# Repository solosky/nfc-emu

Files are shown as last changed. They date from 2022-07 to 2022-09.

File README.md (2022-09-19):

# nfc-emu

这是一个可以模拟NTAG215的模拟器。
可以用来模拟Amiibo和门禁卡。
硬件理论上支持Mifare的卡片，但目前固件不支持。

## 功能

* 支持最多10张卡模拟
* 支持模拟Amiibo
* 4秒无响应自动断电

## PCB 

| RevA | RevB |
| --- | --- |
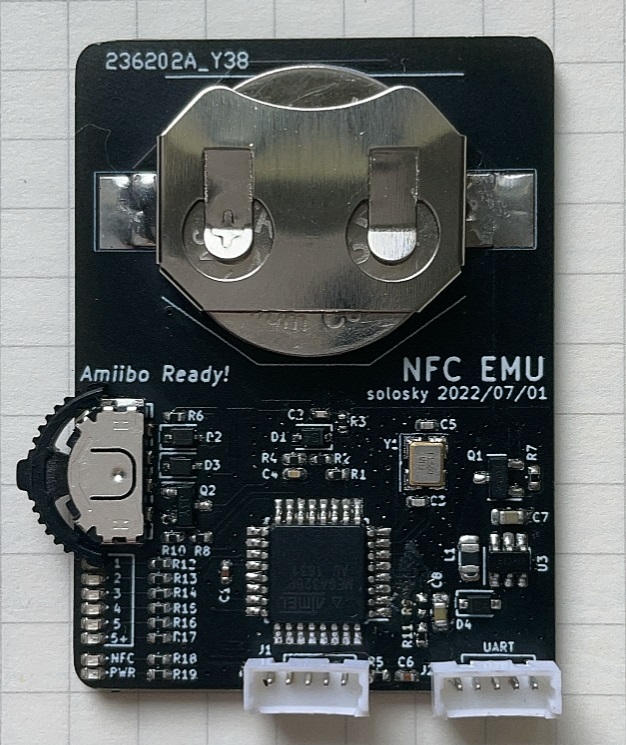
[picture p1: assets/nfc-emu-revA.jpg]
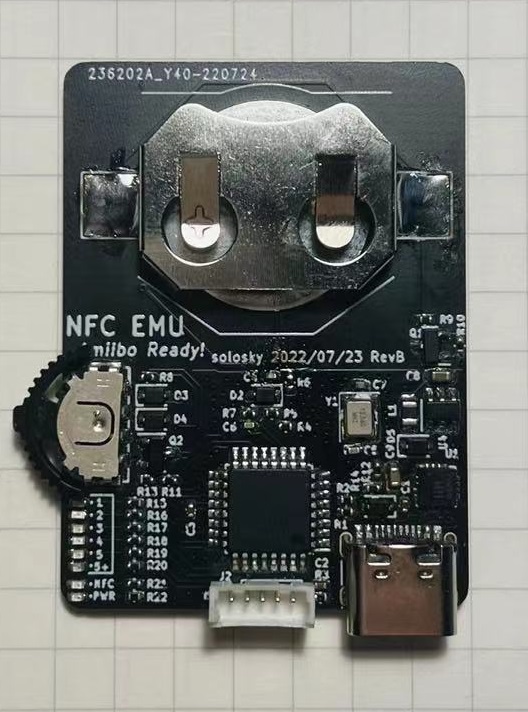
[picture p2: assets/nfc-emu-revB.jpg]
|  |  | 
| 可用 | 和RevA相比新增了CH343P串口芯片，可以直接通过USB下载固件。注意：RevB未能完整测试，使用慎重！！|

## 演示

(https://player.bilibili.com/player.html?aid=688118575&bvid=BV1D24y1Z7Rh&cid=835047325&page=1)

## 固件编译和烧写

本固件是基于Ardunio框架实现的，所以固件烧写方法很类似。
主要分两步，第一步刷入bootloader, 第二步使用串口刷入固件。
bootloader只需要刷写一次即可，之后的固件更新可以直接用串口刷入新固件。

### 刷入Bootloader

需要的软件：progisp 
需要的硬件：USB ISP
* assets/optiboot_flash_atmega328p_UART0_115200_13560000L_B1.hex 刷入MCU中。
* 修改熔丝位：低位值：0xCE, 高位值：0xDE，扩展位：0xFF
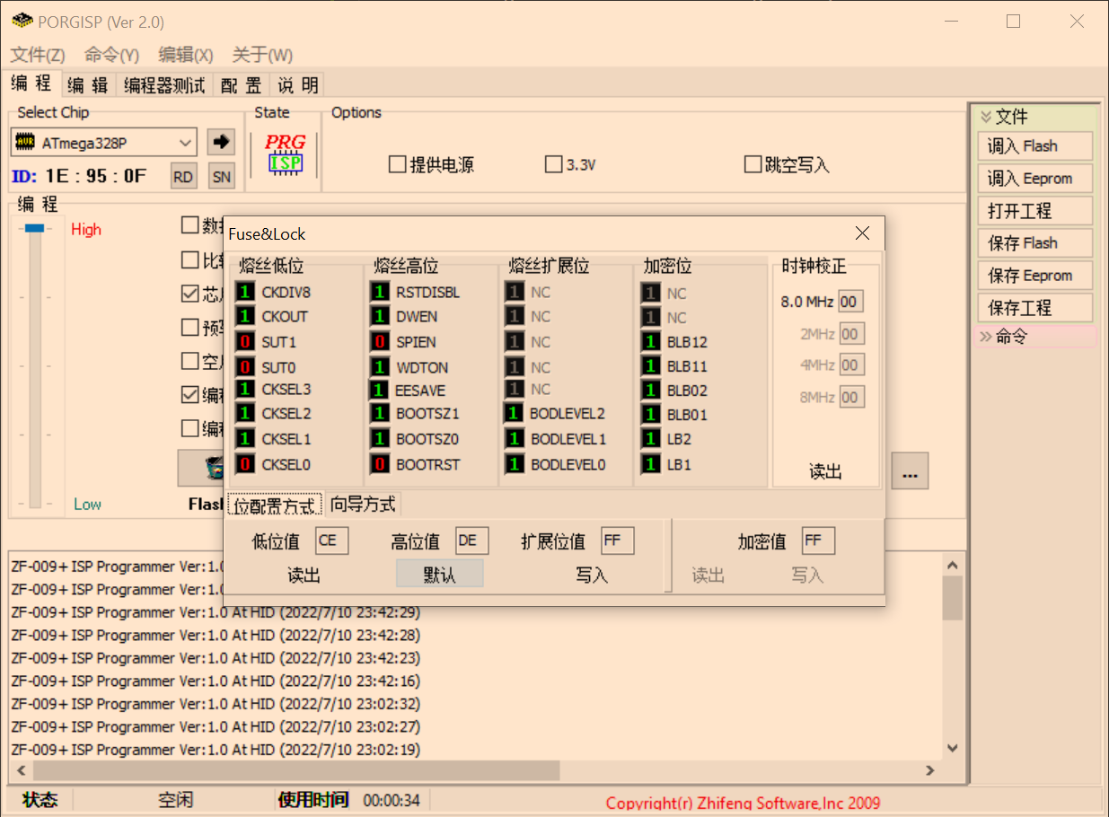
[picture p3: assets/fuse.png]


连接左边标记为ISP的接口到USB ISP烧写器上，接线顺序如下：

CLK MOSI MISO RESET GND 

注意需要把电池安装上，在刷入bootloader过程中需要一直按住中键打开电源。

刷入步骤：
 1. 先点击 编程熔丝 后面的框，弹出熔丝对话框，点击读出按钮读出当前值，然后依次输入 低位值：0xCE, 高位值：0xDE，扩展位：0xFF，点击写入执行写入操作
 2. 点击文件 -> 调入flash, 选择assets/optiboot_flash_atmega328p_UART0_115200_13560000L_B1.hex，点击自动按钮写入bootloader

### 编译固件

首先需要下载 vscode, 安装platformio插件，并安装arduino框架。

因为用了非标准的13.56M的晶振，需要新建一个board。
在 C:\Users\{{用户名}}\.platformio\platforms\atmelavr\boards下面新建一个文件 ATmega328PNfcEmu.json， 内容如下：

```
{
  "build": {
    "core": "MiniCore",
    "extra_flags": "-DARDUINO_AVR_ATmega328P",
    "f_cpu": "13560000L",
    "mcu": "atmega328p",
    "variant": "standard"
  },
  "bootloader": {
    "led_pin": "B5"
  },
  "debug": {
    "simavr_target": "atmega328p",
    "avr-stub": {
      "speed": 115200
    }
  },
  "frameworks": [
    "arduino"
  ],
  "name": "ATmega328P/PA NFC EMU",
  "upload": {
    "maximum_ram_size": 2048,
    "maximum_size": 32768,
    "protocol": "arduino",
    "require_upload_port": true,
    "speed": 115200
  },
  "url": "https://www.microchip.com/wwwproducts/en/ATmega328P",
  "vendor": "Microchip"
}
```

使用vscode打开项目的fw文件夹，platformio插件会自动启动识别为一个platformio的项目。
点击编译按钮就可以完成编译。

### 刷入固件

刷入固件使用vscode的platformio插件完成。

#### RevA 

需要额外一个带DTR信号的USB转串口的模块，连接右边的UART接口按如下顺序连接USB串口模块。

+5V TXD RXD DTR GND 

注意：TXD连串口模块的RXD，RXD连串口模块的TXD。

#### RevB 

自带了的USB转串口模块，直接插上USB线，系统自动识别出串口设备。

#### 刷入步骤

刷入之前，修改platformio.ini中的 upload_port，monitor_port的值为设备的串口号。
点击上传按钮就可以下载固件到设备中。

## 支持的卡

硬件上支持14443-3A的低速卡，比如NTAG215, Mifare等常见卡。
软件层面目前只支持模拟NTAG215，Mifare卡暂时不支持。

## 功耗

目前使用中耗电量为22mA，CR2032勉强能使用，还需要进一步优化电路减少功耗。

因为设计了断电电路，不使用基本不耗电，使用时间取决于使用次数。

注意：一定要使用南孚的传应CR2032电池，其他电池不一定能提供这么大的放电电流！

## 写入TAG

可以用手机APP写入，也可以用PN532等NFC读写器写入。

### 使用手机APP写入

如果手机支持NFC，可以下载如下软件写入Amiibo:

iOS: AppleStore搜索Umiibo写入。
Umiibo是收费软件，但只需要6元RMB，没有应用内购买，很良心的APP的，强烈推荐购买。

Andriod: https://github.com/HiddenRamblings/TagMo/releases 下载最新版本的TAGMO安装。

如果以上都没有，可以购买PN532模块，然后安装Linux虚拟机，将PN532 USB设备接入虚拟机后，执行如下命令写入标签。

### 安装libnfc 

```
sudo apt update
sudo apt install libnfc-dev
```

### Amiibo写入
```
nfc-mfultralight w "SSB Zelda.bin" --full
NFC device: pn532 opened
1 ISO14443A passive target(s) found:
	040402cb5d6480
Using MIFARE Ultralight card with UID: 040402cb5d6480
WARNING: Tag is EV1 or NTAG - PASSWORD may be required
NTAG Type: NTAG215 (504 user bytes)
Checking if UL badge is DirectWrite...
 Original Block 0 (Pages 0-2): 0404028acb5d648072480000
 Original UID: 040402cb5d6480
 Attempt to write Block 0 (pages 0-2) ...
  Writing Page 0: 04 04 02 8a
  Writing Page 1: cb 5d 64 80
  Writing Page 2: 72 48 00 00
 Block 0 written successfully
Card is DirectWrite
Writing 135 pages |.......................................................................................................................................|
Done, 135 of 135 pages written (0 pages skipped, 0 pages failed).

```

默认固件所有标签都是空白的，需要用APP写入标签才能使用。

## 操作说明

* 关机状态下短按中键开机，电源指示灯亮起
* 开机状态下短按上，下键切换标签
* 开机状态下长按中键2秒以上重置标签，uid也会随机生成，标签指示灯会短闪两次
* 开机状态下靠近读卡器读取标签 

可以使用重置标签操作结合APP来无限刷Amiibo!

注意：写入和重置标签会产生Flash的写入操作，一般来说Flash的写入操作是有次数限制的，按ATMEGA328p的手册来说，每扇区至少有10000次写入寿命，所以每个标签的至少能刷写10000次左右（重置和写入算两次操作），超过这个次数当前标签的数据可能永久无法写入。

后续可以考虑实现写均衡来充分利用剩余未使用的空间来提高标签的写入次数。
 
# 感谢 

此项目是移植 [Simple NFC](https://github.com/Nonannet/simple-nfc)，主要的模拟代码来源SimpleNFC，感谢 @Nonannet 提供的代码，非常棒的实现！

# 欢迎加群讨论 

QQ群：109761876

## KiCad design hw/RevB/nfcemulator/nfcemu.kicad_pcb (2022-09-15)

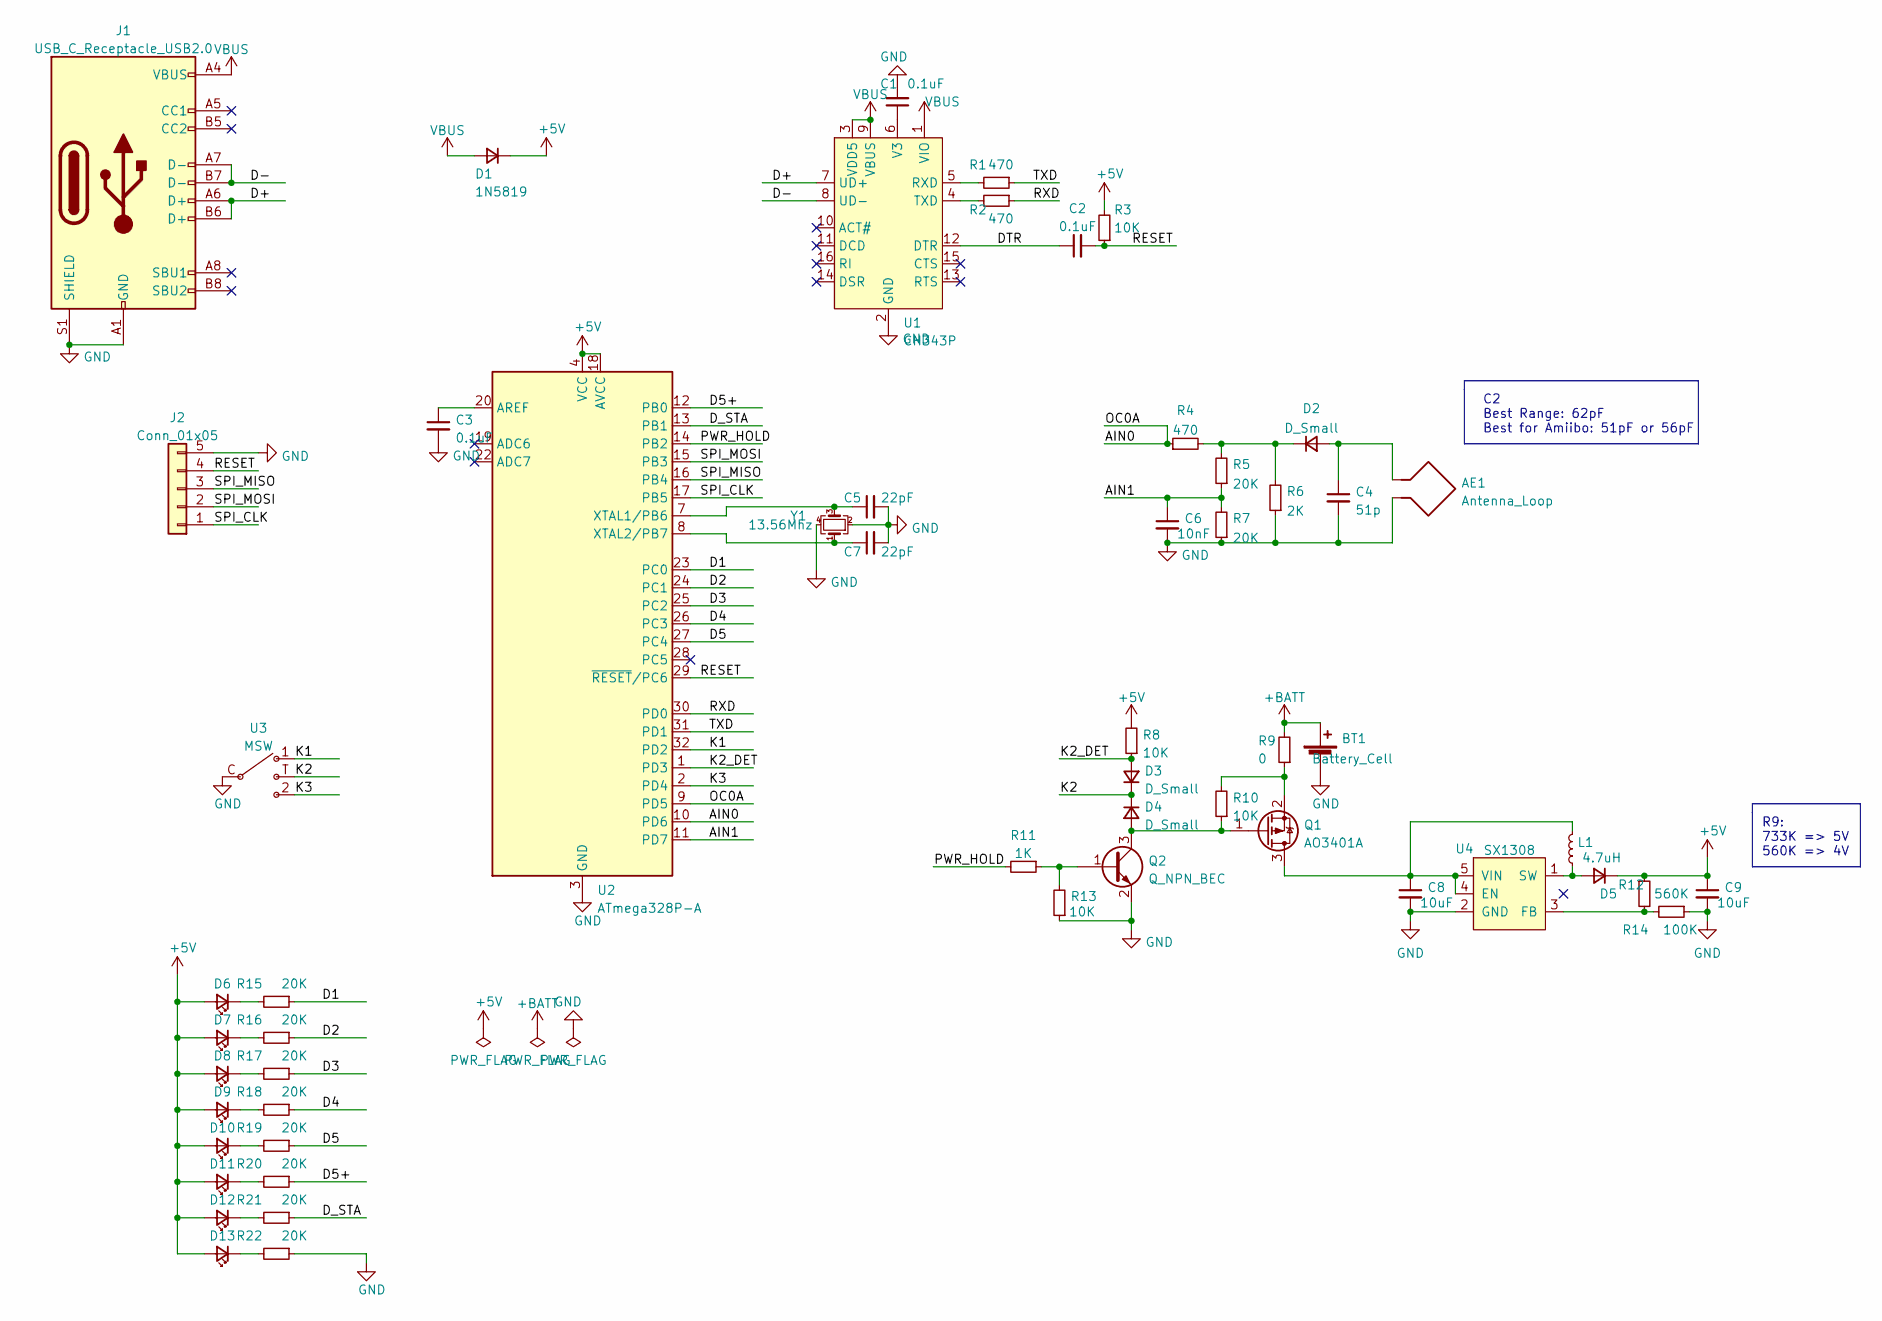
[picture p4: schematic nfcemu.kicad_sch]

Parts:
AE1: Antenna_Loop; NFC_ANT2
BT1: Battery_Cell; BatteryHolder_Keystone_3002_1x2032
C1, C2, C3: 0.1uF; C_0402_1005Metric
C4: 51p; C_0402_1005Metric
C5, C7: 22pF; C_0402_1005Metric
C6: 10nF; C_0402_1005Metric
C8, C9: 10uF; C_0603_1608Metric
D1: 1N5819; D_SOD-323
D2, D3, D4, D5: D_Small; D_SOD-323
D6, D7, D8, D9, D10, D11, D12, D13: LED_Small; LED_0402_1005Metric
J1: USB_C_Receptacle_USB2.0; USB_C_Receptacle_HRO_TYPE-C-31-M-12
J2: Conn_01x05; PinHeader_1x05_P1.27mm_Vertical
L1: 4.7uH; L_0805_2012Metric
Q1: AO3401A; SOT-23
Q2: Q_NPN_BEC; SOT-23
R1, R2, R4: 470; R_0402_1005Metric
R3, R8, R10, R13: 10K; R_0402_1005Metric
R5, R7, R15, R16, R17, R18, R19, R20, R21, R22: 20K; R_0402_1005Metric
R6: 2K; R_0402_1005Metric
R9: 0; R_0402_1005Metric
R11: 1K; R_0402_1005Metric
R12: 560K; R_0402_1005Metric
R14: 100K; R_0402_1005Metric
U1: CH343P; QFN-16-1EP_3x3mm_P0.5mm_EP1.45x1.45mm
U2: ATmega328P-A; TQFP-32_7x7mm_P0.8mm
U3: MSW
U4: SX1308; TSOT-23-6
Y1: 13.56Mhz; Crystal_SMD_3225-4Pin_3.2x2.5mm

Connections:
+5V: C9.1, D1.1 (K), D5.1 (K), D6.2 (A), D7.2 (A), D8.2 (A), D9.2 (A), D10.2 (A), D11.2 (A), D12.2 (A), D13.2 (A), R3.2, R8.2, R12.1, U2.4 (VCC), U2.6 (VCC), U2.18 (AVCC)
+BATT: BT1.1 (+), R9.2
/AIN0: R4.1, U2.9 (PD5), U2.10 (PD6)
/AIN1: C6.1, R5.1, R7.2, U2.11 (PD7)
/D1: R15.1, U2.23 (PC0)
/D2: R16.1, U2.24 (PC1)
/D3: R17.1, U2.25 (PC2)
/D4: R18.1, U2.26 (PC3)
/D5: R19.1, U2.27 (PC4)
/D5+: R20.1, U2.12 (PB0)
/D+: J1.A6 (D+), J1.B6 (D+), U1.7 (UD+)
/D-: J1.A7 (D-), J1.B7 (D-), U1.8 (UD-)
/DTR: C2.1, U1.12 (DTR)
/D_STA: R21.1, U2.13 (PB1)
/K1: U2.32 (PD2), U3.1
/K2: D3.1 (K), D4.1 (K), U3.T
/K2_DET: D3.2 (A), R8.1, U2.1 (PD3)
/K3: U2.2 (PD4), U3.2
/PWR_HOLD: R11.2, U2.14 (PB2)
/RESET: C2.2, J2.4, R3.1, U2.29 (~RESET/PC6)
/RXD: R2.1, U2.30 (PD0)
/SPI_CLK: J2.1, U2.17 (PB5)
/SPI_MISO: J2.3, U2.16 (PB4)
/SPI_MOSI: J2.2, U2.15 (PB3)
/TXD: R1.1, U2.31 (PD1)
GND: AE1.1, BT1.2 (-), C1.2, C3.2, C4.2, C5.2, C6.2, C7.2, C8.2, C9.2, J1.A1 (GND), J1.A12 (GND), J1.B1 (GND), J1.B12 (GND), J1.S1 (SHIELD), J2.5, Q2.2 (E), R6.1, R7.1, R13.1, R14.1, R22.1, U1.2 (GND), U1.17 (EP), U2.3 (GND), U2.5 (GND), U2.21 (GND), U3.C, U4.2 (GND), Y1.2, Y1.4
unnamed: AE1.2, C4.1, D2.2 (A)
unnamed: C1.1, U1.6 (V3)
unnamed: C3.1, U2.20 (AREF)
unnamed: C5.1, U2.7 (XTAL1/PB6), Y1.3
unnamed: C7.1, U2.8 (XTAL2/PB7), Y1.1
unnamed: C8.1, L1.2, Q1.3 (D), U4.4 (EN), U4.5 (VIN)
unnamed: D2.1 (K), R4.2, R5.2, R6.2
unnamed: D4.2 (A), Q1.1 (G), Q2.3 (C), R10.1
unnamed: D5.2 (A), L1.1, U4.1 (SW)
unnamed: D6.1 (K), R15.2
unnamed: D7.1 (K), R16.2
unnamed: D8.1 (K), R17.2
unnamed: D9.1 (K), R18.2
unnamed: D10.1 (K), R19.2
unnamed: D11.1 (K), R20.2
unnamed: D12.1 (K), R21.2
unnamed: D13.1 (K), R22.2
unnamed: Q1.2 (S), R9.1, R10.2
unnamed: Q2.1 (B), R11.1, R13.2
unnamed: R1.2, U1.5 (RXD)
unnamed: R2.2, U1.4 (TXD)
unnamed: R12.2, R14.2, U4.3 (FB)
unnamed: U3.5, U3.6, U3.7, U3.8
VBUS: D1.2 (A), J1.A4 (VBUS), J1.A9 (VBUS), J1.B4 (VBUS), J1.B9 (VBUS), U1.1 (VIO), U1.3 (VDD5), U1.9 (VBUS)

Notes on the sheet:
R9: 733K => 5V 560K => 4V
C2 Best Range: 62pF Best for Amiibo: 51pF or 56pF

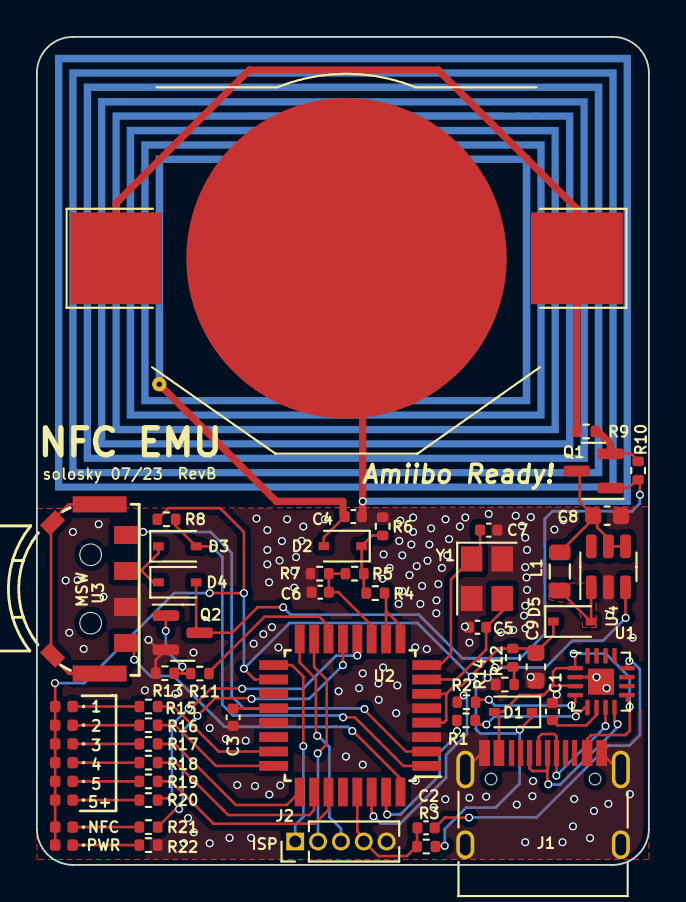
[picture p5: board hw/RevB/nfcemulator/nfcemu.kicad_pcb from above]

Board: 2 copper layers, 34.0 x 46.0 mm, 56 parts (1 on the bottom side), 50 nets.

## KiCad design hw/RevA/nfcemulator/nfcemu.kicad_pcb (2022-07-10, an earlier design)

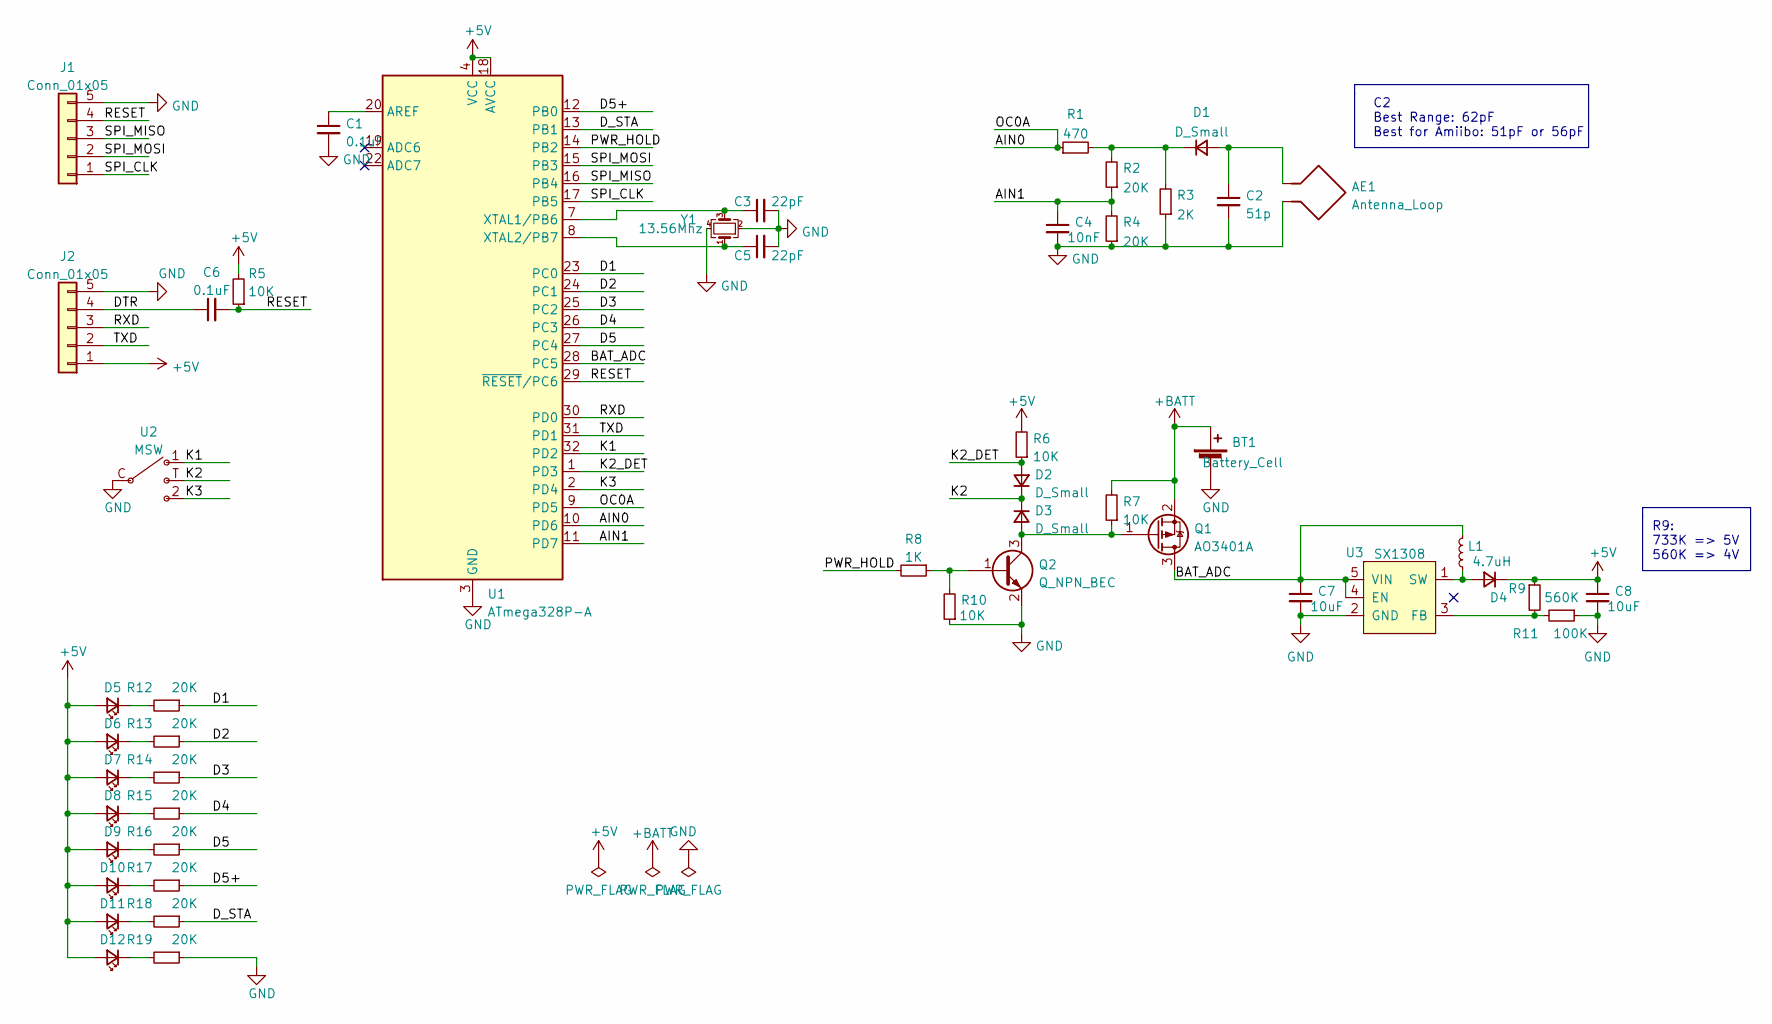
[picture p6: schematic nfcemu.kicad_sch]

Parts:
AE1: Antenna_Loop; NFC_ANT2
BT1: Battery_Cell; BatteryHolder_Keystone_3002_1x2032
C1, C6: 0.1uF; C_0402_1005Metric
C2: 51p; C_0402_1005Metric
C3, C5: 22pF; C_0402_1005Metric
C4: 10nF; C_0402_1005Metric
C7, C8: 10uF; C_0603_1608Metric
D1, D2, D3, D4: D_Small; D_SOD-323
D5, D6, D7, D8, D9, D10, D11, D12: LED_Small; LED_0402_1005Metric
J1, J2: Conn_01x05; PinHeader_1x05_P1.27mm_Vertical
L1: 4.7uH; L_0805_2012Metric
Q1: AO3401A; SOT-23
Q2: Q_NPN_BEC; SOT-23
R1: 470; R_0402_1005Metric
R2, R4, R12, R13, R14, R15, R16, R17, R18, R19: 20K; R_0402_1005Metric
R3: 2K; R_0402_1005Metric
R5, R6, R7, R10: 10K; R_0402_1005Metric
R8: 1K; R_0402_1005Metric
R9: 560K; R_0402_1005Metric
R11: 100K; R_0402_1005Metric
U1: ATmega328P-A; TQFP-32_7x7mm_P0.8mm
U2: MSW
U3: SX1308; TSOT-23-6
Y1: 13.56Mhz; Crystal_SMD_3225-4Pin_3.2x2.5mm

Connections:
+5V: C8.1, D4.1 (K), D5.2 (A), D6.2 (A), D7.2 (A), D8.2 (A), D9.2 (A), D10.2 (A), D11.2 (A), D12.2 (A), J2.1, R5.2, R6.2, R9.1, U1.4 (VCC), U1.6 (VCC), U1.18 (AVCC)
+BATT: BT1.1 (+), Q1.2 (S), R7.2
/AIN0: R1.1, U1.9 (PD5), U1.10 (PD6)
/AIN1: C4.1, R2.1, R4.2, U1.11 (PD7)
/BAT_ADC: C7.1, L1.2, Q1.3 (D), U1.28 (PC5), U3.4 (EN), U3.5 (VIN)
/D1: R12.1, U1.23 (PC0)
/D2: R13.1, U1.24 (PC1)
/D3: R14.1, U1.25 (PC2)
/D4: R15.1, U1.26 (PC3)
/D5: R16.1, U1.27 (PC4)
/D5+: R17.1, U1.12 (PB0)
/DTR: C6.1, J2.4
/D_STA: R18.1, U1.13 (PB1)
/K1: U1.32 (PD2), U2.1
/K2: D2.1 (K), D3.1 (K), U2.T
/K2_DET: D2.2 (A), R6.1, U1.1 (PD3)
/K3: U1.2 (PD4), U2.2
/PWR_HOLD: R8.2, U1.14 (PB2)
/RESET: C6.2, J1.4, R5.1, U1.29 (~RESET/PC6)
/RXD: J2.3, U1.30 (PD0)
/SPI_CLK: J1.1, U1.17 (PB5)
/SPI_MISO: J1.3, U1.16 (PB4)
/SPI_MOSI: J1.2, U1.15 (PB3)
/TXD: J2.2, U1.31 (PD1)
GND: AE1.1, BT1.2 (-), C1.2, C2.2, C3.2, C4.2, C5.2, C7.2, C8.2, J1.5, J2.5, Q2.2 (E), R3.1, R4.1, R10.1, R11.1, R19.1, U1.3 (GND), U1.5 (GND), U1.21 (GND), U2.C, U3.2 (GND), Y1.2, Y1.4
unnamed: AE1.2, C2.1, D1.2 (A)
unnamed: C1.1, U1.20 (AREF)
unnamed: C3.1, U1.7 (XTAL1/PB6), Y1.3
unnamed: C5.1, U1.8 (XTAL2/PB7), Y1.1
unnamed: D1.1 (K), R1.2, R2.2, R3.2
unnamed: D3.2 (A), Q1.1 (G), Q2.3 (C), R7.1
unnamed: D4.2 (A), L1.1, U3.1 (SW)
unnamed: D5.1 (K), R12.2
unnamed: D6.1 (K), R13.2
unnamed: D7.1 (K), R14.2
unnamed: D8.1 (K), R15.2
unnamed: D9.1 (K), R16.2
unnamed: D10.1 (K), R17.2
unnamed: D11.1 (K), R18.2
unnamed: D12.1 (K), R19.2
unnamed: Q2.1 (B), R8.1, R10.2
unnamed: R9.2, R11.2, U3.3 (FB)
unnamed: U2.5, U2.6, U2.7, U2.8

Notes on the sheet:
R9: 733K => 5V 560K => 4V
C2 Best Range: 62pF Best for Amiibo: 51pF or 56pF

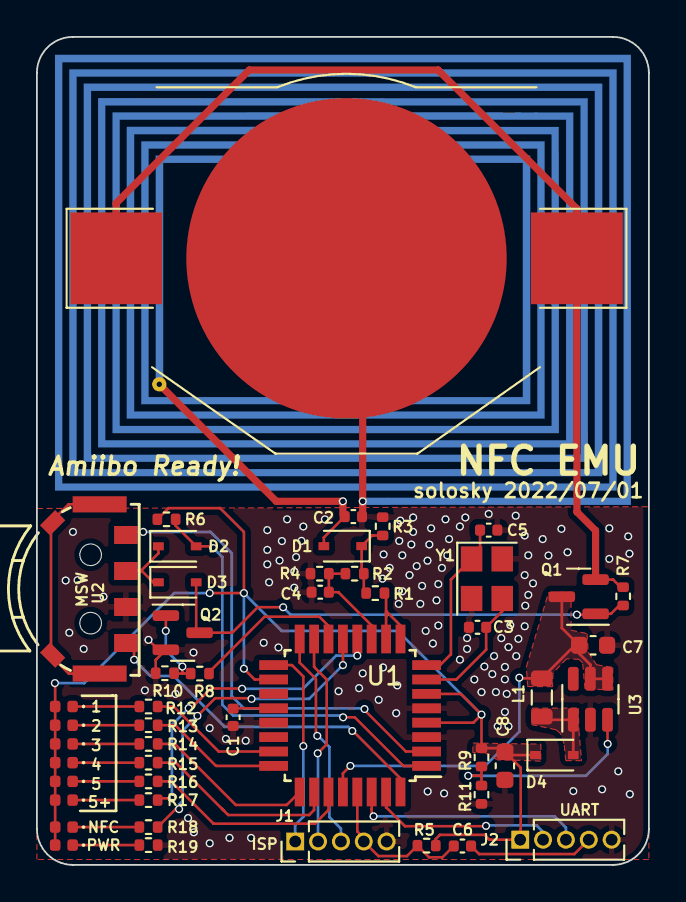
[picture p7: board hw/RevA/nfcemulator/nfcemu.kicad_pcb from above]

Board: 2 copper layers, 34.0 x 46.0 mm, 50 parts (1 on the bottom side), 43 nets.

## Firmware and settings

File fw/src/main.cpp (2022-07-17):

#include <Arduino.h>
#include <avr/interrupt.h>
#include <avr/io.h>
#include <avr/power.h>
#include <avr/sleep.h>
#include <avr/wdt.h>
#include <util/delay.h>

#include "button.h"
#include "led.h"
#include "nfc.h"
#include "nfcemulator.h"
#include "storage.h"
#include "timer2.h"

void power_hold() {
  DDRB |= _BV(DDB2);
  PORTB |= _BV(PORTB2);
}

void power_off() {
  PORTB &= ~_BV(PORTB2);
  DDRB &= ~_BV(DDB2);
}

void power_disable_unused() { PRR = _BV(PRTWI) | _BV(PRSPI); }

void wdt_init() {
  cli();
  wdt_reset();
  MCUSR &= ~(1 << WDRF);
  WDTCSR = _BV(WDCE) | _BV(WDE);
  WDTCSR = _BV(WDP3);  // 4s timeout
  WDTCSR |= (1 << WDIE);
  sei();
}

ISR(WDT_vect) {
  // wdt_reset();
  nfc_save();
  power_off();
}

int main() {
  sei();

  Serial.begin(115200);
  Serial.print("NFC EMU v1.0");
  wdt_init();

  _delay_ms(100);

  power_hold();

  timer2_init();
  button_init();
  led_init();
  storage_init();

  led_sta_off();

  power_disable_unused();

  nfc_init();
  while (1) {
    nfc_tick();
    button_tick();
  }
}

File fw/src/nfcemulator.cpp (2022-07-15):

/*****************************************************************************
Written and Copyright (C) by Nicolas Kruse

Licensed under the Apache License, Version 2.0 (the "License");
you may not use this file except in compliance with the License.
You may obtain a copy of the License at

http://www.apache.org/licenses/LICENSE-2.0

Unless required by applicable law or agreed to in writing, software
distributed under the License is distributed on an "AS IS" BASIS,
WITHOUT WARRANTIES OR CONDITIONS OF ANY KIND, either express or implied.
See the License for the specific language governing permissions and
limitations under the License.
*****************************************************************************/

#include "nfcemulator.h"

#include <Arduino.h>
#include <avr/interrupt.h>
#include <avr/io.h>
#include <avr/pgmspace.h>
#include <avr/wdt.h>
#include <string.h>
#include <util/delay.h>

static uint8_t RX_MASK[18] = {0,  1, 0,  2, 0,  4, 0,   8, 0,
                              16, 0, 32, 0, 64, 0, 128, 0, 0};
static uint8_t TX_MASK[8] = {1, 2, 4, 8, 16, 32, 64, 128};
static uint16_t FDT_DELAY[2] = {FDT_DELAY_BIT0, FDT_DELAY_BIT1};

static uint8_t REQA[1] = {0x26};
static uint8_t WUPA[1] = {0x52};
static uint8_t HLTA[4] = {0x50, 0x00, 0x57, 0};  //'50' '00' CRC_A
static uint8_t ATQA[2] = {0x44, 0x00};  // Anticollision with udi size = double
static uint8_t SEL_CL1[2] = {0x93, 0x20};
static uint8_t SEL_CL2[2] = {0x95, 0x20};
static uint8_t CT_UID1[5] = {0x88, 0x04, 0xE3, 0xEF,
                             0};  // uid0 uid1 uid2 uid3 BCC
static uint8_t UID2[5] = {0xA2, 0xEF, 0x20, 0x80, 0};  // uid3 uid4 uid5 uid6
                                                       // BCC
static uint8_t SAK_NC[3] = {0x04, 0xDA,
                            0x17};  // Select acknowledge uid not complete
static uint8_t SAK_C[3] = {0x00, 0xFE,
                           0x51};  // Select acknowledge uid complete, Type 2
                                   // (PICC not compliant to ISO/IEC 14443-4)
static uint8_t comp_write_pages = -1;
static bool comp_write_pending = false;
static bool storage_dirty = false;

#define CMD_GET_VERSION 0x60
#define CMD_AUTH 0x1b
#define CMD_GET_SIG 0x3c
#define CMD_FAST_READ 0x3a
#define CMD_READ 0x30
#define CMD_WRITE 0xA2
#define CMD_COMPATIBILITY_WRITE 0xa0

#define AIN1_PORT PORTD
#define AIN1_BIT PORTD7

#define PAGE_LOCKS 2
#define PAGE_PWD 133
#define PAGE_PACK 134

uint8_t *sto;      // Pointer to tag content
uint16_t stoSize;  // Number of avalible bytes on the tag

uint8_t buffer[250];
uint8_t rCount = 0;

emu_event_callback_t emu_event_callback = NULL;

#define LED_OFF (PORTB |= _BV(PORTB1))
#define LED_ON (PORTB &= ~_BV(PORTB1))

#define OC_OUTPUT DDRD |= (1 << 5)
#define OC_INPUT DDRD &= ~(1 << 5)

void addCrc16(uint8_t *Data, uint8_t Length);
void addBcc(uint8_t *Data);

void emu_set_event_callback(emu_event_callback_t callback) {
  emu_event_callback = callback;
}

void initNfcEmulator() {
  // clock divider for 8 bit timer0: clk/1 -> 13.5225 MHz
  TCCR0B |= (1 << CS00);

  // 8 bit timer0: Toggle OC0A on Compare Match and CTC-Mode
  // for 847.5 kHz subcarrier
  TCCR0A |= (1 << COM0B0) | (1 << WGM01);

  // set up 847.5 kHz subcarrier for sending (8 bit timer0)
  OCR0A = SUBC_OVF;

  // CTC-Mode and no clock divider for 16 bit timer1: clk/1
  TCCR1B = (1 << WGM12) | (1 << CS10);

  // Setup Analog Comparator, Enable (ACD), Set Analog Comparator
  // Interrupt Flag on Rising Output Edge (ACIS0, ACIS1)
  ACSR = (0 << ACD) | (1 << ACIS0) | (1 << ACIS1);

  AIN1_PORT |= (1 << AIN1_BIT);
}

void setupNfcEmulator(uint8_t *storage, uint16_t storageSize) {
  CT_UID1[1] = storage[0];
  CT_UID1[2] = storage[1];
  CT_UID1[3] = storage[2];

  UID2[0] = storage[4];
  UID2[1] = storage[5];
  UID2[2] = storage[6];
  UID2[3] = storage[7];

  addCrc16(HLTA, 2);
  addBcc(CT_UID1);
  addBcc(UID2);

  stoSize = storageSize;
  sto = storage;
}

void addCrc16(uint8_t *Data, uint8_t Length) {
  uint8_t ch;
  uint16_t wCrc = 0x6363;  // ITU-V.41

  do {
    ch = *Data++;

    ch = (ch ^ (uint8_t)((wCrc)&0x00FF));
    ch = (ch ^ (ch << 4));
    wCrc = (wCrc >> 8) ^ ((uint16_t)ch << 8) ^ ((uint16_t)ch << 3) ^
           ((uint16_t)ch >> 4);
  } while (--Length);

  *Data = (uint8_t)(wCrc & 0xFF);
  Data++;
  *Data = (uint8_t)((wCrc >> 8) & 0xFF);
}

void addBcc(uint8_t *Data)  // add exclusive-OR of 4 bytes
{
  Data[4] = Data[0] ^ Data[1] ^ Data[2] ^ Data[3];
}

void waitForBitend() {
  while (!(TIFR1 & (1 << OCF1A)))
    ;  // Wait till end of bit-time
  TIFR1 |= (1 << OCF1A);
}

#if (F_CPU == RFID_FREQU)
void waitForOneBitTime() { waitForBitend(); }
#elif (F_CPU == 22000000UL)
// Skip every 17 bit times 1 cycle
void waitForOneBitTime() {
  if (rCount < 7) {
    OCR1AL = CLC_PBIT / 2 - 1;
    rCount++;
  } else {
    OCR1AL = CLC_PBIT / 2 - 2;
    rCount = 0;
  }
  waitForBitend();
}
#elif (F_CPU == 13592500UL)
// Add every 6 bit times 1 cycle
void waitForOneBitTime() {
  if (rCount < 6) {
    OCR1AL = CLC_PBIT / 2 - 1;
    rCount++;
  } else {
    OCR1AL = CLC_PBIT / 2;
    rCount = 0;
  }
  waitForBitend();
}
#else
//#error "Not supported frequency, please add support if possible"
void waitForOneBitTime() {}

#endif

void txManchester(uint8_t *data, uint8_t length) {
  uint8_t txBytePos = 0;
  uint8_t txbitPos = 0;
  uint8_t parity = 0;

  TIFR1 |= (1 << OCF1A);

  // Send SOC
  waitForBitend();
  OC_OUTPUT;
  OCR1A = CLC_PBIT / 2 - 1;  // Set Hi- and Low-Bit
  waitForOneBitTime();
  OC_INPUT;

  do {
    if (TX_MASK[txbitPos] & data[txBytePos]) {
      waitForOneBitTime();
      OC_OUTPUT;
      parity ^= 1;
      waitForOneBitTime();
      OC_INPUT;
    } else {
      waitForOneBitTime();
      OC_INPUT;
      waitForOneBitTime();
      OC_OUTPUT;
    }

    txbitPos++;

    if (txbitPos > 7) {
      if (parity) {
        waitForOneBitTime();
        OC_INPUT;
        waitForOneBitTime();
        OC_OUTPUT;
      } else {
        waitForOneBitTime();
        OC_OUTPUT;
        waitForOneBitTime();
        OC_INPUT;
      }

      txBytePos++;
      txbitPos = 0;
      parity = 0;
    }
  } while (txBytePos < length);

  // Send EOC
  waitForOneBitTime();
  OC_INPUT;
}
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

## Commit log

2022-07-10 init commit
    [nfcemu.kicad_pcb, nfcemu.kicad_sch]
2022-07-17 fix power off failed issue
    [main.cpp]
2022-09-15 add RevB: onboard UART chip ch343p
    [nfcemu.kicad_pcb, nfcemu.kicad_sch]
2022-09-16 更新readme, 删除默认的卡片
2022-09-18 新增标签重置功能
2022-09-18 更新README
2022-09-19 修复长按可能重启问题和更新readme
